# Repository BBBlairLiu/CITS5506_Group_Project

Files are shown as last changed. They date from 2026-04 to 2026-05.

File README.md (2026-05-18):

# SmartSan IoT Group Project

SmartSan is an IoT-based hand sanitiser monitoring system designed for CITS5506.  
The current prototype design combines automatic dispensing, sanitizer level monitoring, and a simple browser-based monitoring interface.

## Current Repository Status

This repository currently includes a mock dashboard, software planning documents, and an ESP32 firmware skeleton for the SmartSan system.

At this stage:
- the dashboard is built with HTML, CSS, and JavaScript
- the displayed values are **mock data following the planned ESP32/Blynk data contract**
- the firmware can run with simulated hardware while the real components are in transit
- the page is intended to simulate the future monitoring workflow before hardware arrives

## Current Design Overview

The current SmartSan design is based on:
- **ESP32** as the main controller
- **VL53L1X distance sensor** for hand detection
- **servo motor** for bottle pressing
- **HX711 load cell** for weight-based refill estimation
- **Blynk dashboard** as the primary mobile dashboard
- **local browser interface** as a mock/demo fallback

The current software flow is planned as:

Distance sensor detects hand -> servo presses bottle -> usage count updates -> liquid weight and remaining percentage are updated -> refill status is checked -> status is sent to Blynk/dashboard

## Dashboard Features (Mock Version)

The current dashboard shows:
- usage count
- liquid weight
- remaining level percentage
- sanitizer status
- device state
- device online state
- refill threshold
- last dispense time
- sync status and last sync time
- last updated time

It also includes demo controls for simulated sensor dispense, manual dispense, alert reset, system enable/disable, simulated sync failure, and an event timeline.

## Firmware Skeleton

The ESP32 Arduino sketch is available at:

- `firmware/SmartSanESP32/SmartSanESP32.ino`

By default, the sketch uses mock hardware mode:

- Serial Monitor input `d` simulates a valid hand-detection event
- Blynk virtual pins are updated using the planned dashboard data contract
- hardware adapter functions are isolated so they can later be replaced with real IR, servo, and HX711 logic

Before uploading to an ESP32, copy `firmware/SmartSanESP32/secrets.example.h` to `firmware/SmartSanESP32/secrets.h` and fill in local Blynk and Wi-Fi values. The local `secrets.h` file is ignored by git.

For team testing instructions, follow `docs/team_testing_guide.md`.

## Software Documents

- `docs/software_functionalities.md` summarises the software features.
- `docs/blynk_dashboard.md` defines the Blynk dashboard widgets and virtual pins.
- `docs/data_contract.md` defines the fields shared between firmware and dashboard.
- `docs/integration_test_plan.md` lists the hardware integration and evidence checklist.
- `docs/software_test_checklist.md` lists software-only validation scenarios before hardware integration.
- `docs/team_testing_guide.md` gives the step-by-step Blynk, mock firmware, and hardware test handoff.

## How to Run

Open the dashboard file in a browser.

### Option 1
Open the HTML file directly:
- `src/index.html`

### Option 2
Use **Live Server** in VS Code:
1. Open the project in VS Code
2. Right-click the HTML file
3. Select **Open with Live Server**

## Project Structure

```text
CITS5506_GROUP_PROJECT/
├─ docs/
│  ├─ blynk_dashboard.md
│  ├─ data_contract.md
│  ├─ integration_test_plan.md
│  ├─ software_test_checklist.md
│  └─ software_functionalities.md
├─ firmware/
│  └─ SmartSanESP32/
│     └─ SmartSanESP32.ino
├─ src/
│  └─ index.html
└─ README.md

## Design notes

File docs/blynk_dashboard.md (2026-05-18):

# SmartSan Blynk Dashboard Setup

This project uses Blynk as the primary dashboard platform because it gives the team a mobile-friendly demo quickly while the hardware and 3D printed enclosure are still being prepared.

## Blynk Template

Create one Blynk template for the prototype:

- Template name: `SmartSan Prototype`
- Hardware: `ESP32`
- Connection type: `WiFi`
- Device name: `SmartSan Demo Unit`

Keep Adafruit IO as a backup for data logging only. The main demo should use Blynk first so the flow is easy to show on a phone.

## Virtual Pin Map

| Virtual Pin | Field | Type | Unit | Direction | Suggested Widget |
| --- | --- | --- | --- | --- | --- |
| `V0` | `usageCount` | Integer | events | ESP32 to Blynk | Value Display |
| `V2` | `remainingPercent` | Integer | % | ESP32 to Blynk | Gauge |
| `V3` | `refillAlert` | Integer | 0/1 | ESP32 to Blynk | LED or Label |
| `V4` | `deviceState` | String | none | ESP32 to Blynk | Label |
| `V5` | `lastDispenseAt` | String | time | ESP32 to Blynk | Label |
| `V6` | `deviceOnline` | Integer | 0/1 | ESP32 to Blynk | LED |
| `V7` | `liquidWeightGrams` | Double | g | ESP32 to Blynk | Value Display or Chart |
| `V8` | `distanceMm` | Integer | mm | ESP32 to Blynk | Value Display |
| `V9` | `lastDispenseGrams` | Double | g | ESP32 to Blynk | Value Display |
| `V10` | `manualDispense` | Integer | 0/1 | Blynk to ESP32 | Button |
| `V11` | `resetAlert` | Integer | 0/1 | Blynk to ESP32 | Button |
| `V12` | `systemEnabled` | Integer | 0/1 | Blynk to ESP32 | Switch |

## Blynk Console Changes for Weight-Based Firmware

Update the existing template datastreams before uploading the hardware-enabled firmware:

1. Edit `V7`:
   - Name: `liquidWeightGrams`
   - Data type: `Double`
   - Units: `g`
   - Min: `0`
   - Max: `700`
   - Decimals: `1`
2. Add `V8`:
   - Name: `distanceMm`
   - Data type: `Integer`
   - Units: `mm`
   - Min: `0`
   - Max: `2000`
3. Add `V9`:
   - Name: `lastDispenseGrams`
   - Data type: `Double`
   - Units: `g`
   - Min: `0`
   - Max: `100`
   - Decimals: `1`
4. Keep `V2` as `remainingPercent` with Min `0`, Max `100`, and units `%`.
5. Keep `V3` as `refillAlert` with Min `0`, Max `1`.
6. Click **Save And Apply** after editing the datastreams.

## Dashboard Layout

Use this layout for the first demo:

- Top row: device online, system state, refill alert.
- Main metrics: usage count, liquid weight, remaining percentage.
- Diagnostics: distance reading and last dispense grams.
- Activity: last dispense time.
- Controls: manual dispense, reset alert, system enable switch.

## Update Rules

- Send status updates every 5 seconds while idle.
- Send immediate updates after a valid dispense event.
- Send immediate updates when refill alert changes.
- Treat `refillAlert = 1` when `remainingPercent <= 10`.
- Use `systemEnabled = 0` to block manual and sensor-triggered dispensing during testing.

## Demo Notes

The Blynk dashboard should be ready before the hardware arrives. During early testing, the ESP32 sketch can send simulated values to these virtual pins so the team can verify the dashboard workflow without sensors connected.

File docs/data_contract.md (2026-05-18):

# SmartSan Data Contract

This document defines the software interface between the ESP32 firmware, the Blynk dashboard, and the local mock dashboard.

## Status Payload

| Field | Type | Unit | Source | Update Frequency | Description |
| --- | --- | --- | --- | --- | --- |
| `usageCount` | Integer | events | ESP32 state | After dispense and every 5 seconds | Total valid dispense events since reset |
| `liquidWeightGrams` | Float | g | HX711 load cell | Every 5 seconds and after dispense | Estimated remaining liquid weight after empty-bottle tare |
| `remainingPercent` | Integer | % | ESP32 calculation | After measurement and after dispense | Estimated sanitizer remaining percentage from liquid weight |
| `distanceMm` | Integer | mm | VL53L1X distance sensor | Every 5 seconds and during detection | Corrected hand-distance reading |
| `lastDispenseGrams` | Float | g | ESP32 calculation | After dispense stabilisation | Estimated liquid used by the latest accepted dispense |
| `refillAlert` | Boolean | none | ESP32 threshold logic | On change and every 5 seconds | `true` when refill is required |
| `deviceState` | String | none | ESP32 state machine | On state change | Current software state |
| `deviceOnline` | Boolean | none | ESP32/Blynk connection | Every 5 seconds | Whether the device is connected |
| `systemEnabled` | Boolean | none | Blynk/local control | On change | Allows or blocks dispensing |
| `handDetected` | Boolean | none | VL53L1X distance range | During detection and state update | Whether a valid hand event is active |
| `lastDispenseAt` | String | time | ESP32 clock/runtime | After dispense | Last successful dispense timestamp or runtime label |
| `message` | String | none | ESP32 state machine | On state change | Human-readable dashboard message |

## State Values

Use these values consistently in firmware and dashboard displays:

- `IDLE`
- `HAND_DETECTED`
- `DISPENSING`
- `WAIT_STABILISE`
- `CHECK_REFILL`
- `UPDATE_STATUS`
- `REFILL_REQUIRED`
- `DISABLED`
- `ERROR`

## Thresholds and Timing

| Name | Default | Purpose |
| --- | --- | --- |
| `fullLiquidGrams` | `600 g` | Weight used as the full-liquid calibration reference for the demo |
| `refillAlertPercent` | `10%` | Trigger refill alert when remaining percentage is at or below this value |
| `minHandDistanceMm` | `70 mm` | Lower bound of distance-trigger detection range |
| `maxHandDistanceMm` | `150 mm` | Upper bound of distance-trigger detection range |
| `dispenseLockoutMs` | `2000 ms` | Prevent repeated dispensing from one hand gesture |
| `stabiliseDelayMs` | `1200 ms` | Wait after servo movement before calculating post-dispense weight |
| `statusIntervalMs` | `5000 ms` | Regular idle dashboard update interval |

## Alert Logic

The remaining percentage is:

```text
remainingPercent = clamp((liquidWeightGrams / fullLiquidGrams) * 100, 0, 100)
```

The refill condition is:

```text
refillAlert = remainingPercent <= refillAlertPercent
```

The latest dispense amount is:

```text
lastDispenseGrams = max(previousLiquidWeightGrams - currentLiquidWeightGrams, 0)
```

## Control Inputs

| Control | Source | Expected Value | Behaviour |
| --- | --- | --- | --- |
| `manualDispense` | Blynk button or mock dashboard | `1` when pressed | Runs one dispense cycle if `systemEnabled = true` |
| `resetAlert` | Blynk button or mock dashboard | `1` when pressed | Clears the visible alert after refill/testing |
| `systemEnabled` | Blynk switch or mock dashboard | `0` or `1` | Disables or enables automatic and manual dispensing |

## Hardware-Abstraction Rule

Before hardware arrives, firmware functions may return simulated values. After hardware arrives, the hardware adapter functions should remain isolated:

- `readHandDetected()`
- `performDispense()`
- `readWeightMeasurement()`
- `sampleMeasurements()`

The state machine, Blynk virtual pin mapping, and dashboard fields should remain unchanged.

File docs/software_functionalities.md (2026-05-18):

# SmartSan Software Functionalities

This document summarises the software functionalities for the current SmartSan design.

## Current Design Context

The current SmartSan prototype is based on:
- ESP32 as the main controller
- VL53L1X distance sensor for hand detection
- Servo motor for bottle pressing
- HX711 load cell for sanitizer liquid-weight monitoring
- Blynk dashboard as the primary mobile interface
- Local browser interface as a mock/demo fallback

The current direction is to:
- use liquid weight as the current level-monitoring method
- keep pump-count estimation only as a mock-mode fallback
- use the distance sensor as the primary automatic trigger
- focus first on a reliable monitoring workflow instead of advanced analytics
- use simulated sensor values before hardware arrives so the software flow can be tested early

---

## Main Software Functions

### 1. Hand Detection
The system continuously reads the VL53L1X distance sensor and decides whether a valid hand-detection event has occurred.

**Purpose**
- detect a user hand in the valid sensing range
- avoid false triggers from small fluctuations

**Input**
- corrected distance reading in millimetres

**Output**
- `handDetected = true/false`

---

### 2. Dispensing Control
Once a valid hand is detected, the ESP32 triggers the servo motor to press the sanitizer bottle once and return to its initial position.

**Purpose**
- perform one valid dispense action
- prevent repeated dispensing from one gesture

**Input**
- `handDetected`

**Output**
- one dispense event
- servo press-and-return cycle completed

---

### 3. Usage Event Recording
Each successful dispense is recorded as one valid usage event.

**Purpose**
- track how many times the dispenser has been used
- connect physical action to monitoring data

**Input**
- dispense event

**Output**
- `usageCount++`
- latest usage event updated

---

### 4. Liquid Weight Tracking
The system tracks the estimated grams of liquid left in the current refill cycle.

**Purpose**
- provide a practical remaining-level estimate from the calibrated load cell

**Input**
- HX711 raw reading
- empty-bottle zero point
- calibration factor

**Output**
- `liquidWeightGrams`
- `remainingPercent`

---

### 5. Dispense Lockout and Stabilisation Window
The system applies lockout and delay logic to avoid repeated dispensing from one gesture.

**Purpose**
- prevent accidental rapid re-triggering
- keep event counting reliable during servo motion

**Logic**
- lockout period after dispense
- state transition delay before refill check

**Output**
- one counted event per accepted dispense cycle

---

### 6. Sanitizer Level Monitoring
The remaining percentage is compared with a refill threshold to determine whether the sanitizer level is normal or low.

**Purpose**
- monitor remaining sanitizer level
- support condition-based refill alerts

**Input**
- `liquidWeightGrams`
- `remainingPercent`
- `refillAlertPercent`

**Output**
- `sanitizerLow = true/false`

---

### 7. Refill Alert Logic
When the sanitizer level falls below the refill threshold, the system updates the warning state.

**Purpose**
- provide a clear low-sanitizer alert

**Input**
- `sanitizerLow`

**Output**
- `warningStatus = LOW/NORMAL`

---

### 8. Device State Management
The software manages the sequence of system states so the workflow happens in the correct order.

**Purpose**
- keep the workflow organised
- make debugging easier

**Example States**
- `IDLE`
- `HAND_DETECTED`
- `DISPENSING`
- `WAIT_STABILISE`
- `CHECK_REFILL`
- `UPDATE_STATUS`

---

### 9. Wi-Fi / Blynk Status Transmission
The ESP32 sends the latest system variables to Blynk and can also support the local browser mock interface during development.

**Purpose**
- make monitoring information visible through the web page

**Input**
- usage count
- sanitizer status
- device state

**Output**
- updated values available to the dashboard

---

### 10. Web Monitoring Display and Sync Status
The browser page shows key monitoring information plus sync health for testing without hardware.

**Current Display Fields**
- usage count
- liquid weight
- remaining percentage
- sanitizer status
- device state
- refill threshold
- system message
- sync status and event timeline

---

## Suggested MVP Workflow

The current minimum viable software flow is:

`distance sensor detects hand -> servo presses bottle -> usage count updates -> liquid weight is updated -> refill status is checked -> status is sent by Wi-Fi -> browser page displays result`

---

## Current Priority

The current software priority is:
1. hand detection
2. dispensing control
3. usage event recording
4. liquid weight tracking
5. lockout and stabilisation window
6. sanitizer level monitoring
7. refill alert logic
8. Wi-Fi status transmission
9. web monitoring display

The implementation details are split across:
- `blynk_dashboard.md` for Blynk virtual pins and widgets
- `data_contract.md` for shared ESP32/dashboard fields
- `integration_test_plan.md` for hardware arrival and final demo testing

---

## Not the Current Priority

At this stage, the software should not focus too much on:
- advanced analytics
- prediction models
- too many admin-side functions
- advanced prediction beyond the current distance/weight workflow

These can be considered later after the basic monitoring workflow is stable.

---

## Summary

The software for the current SmartSan design is intended to support:
- automatic hand detection
- controlled dispensing
- usage recording
- weight-based level monitoring
- refill warning
- browser-based monitoring

The main goal for this stage is to build a simple, reliable, and testable monitoring workflow before full hardware integration.

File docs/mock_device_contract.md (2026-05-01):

# SmartSan Firmware Output Contract

## Update Behaviour

Immediate update on:
- state change
- valid dispense
- refill reset
- system enable/disable

Periodic idle update:
- every 5 seconds

---

## Output Fields

| Field | Type | Unit | Example | Update Trigger |
|---|---|---|---|---|
| usageCount | integer | events | 14 | dispense + periodic |
| remainingPumps | integer | pumps | 11 | dispense + reset |
| remainingPercent | integer | % | 44 | dispense + reset |
| refillAlert | boolean | true/false | false | refill threshold |
| deviceState | string | enum | IDLE | state transition |
| deviceOnline | boolean | true/false | true | periodic |
| lastDispenseAt | string | ms/time | 124920 | dispense |

---

## State Enum Values

- IDLE
- HAND_DETECTED
- DISPENSING
- WAIT_STABILISE
- CHECK_REFILL
- UPDATE_STATUS
- REFILL_REQUIRED
- DISABLED
- ERROR

---

# Mock Trace 1 — Normal Dispense

t=0s  
state=IDLE  
remainingPumps=25  
refillAlert=false

t=1s  
state=HAND_DETECTED

t=2s  
state=DISPENSING

t=3s  
state=WAIT_STABILISE

t=4s  
state=CHECK_REFILL  
remainingPumps=24

t=5s  
state=UPDATE_STATUS

t=6s  
state=IDLE

---

# Mock Trace 2 — Refill Required

t=0s  
state=IDLE  
remainingPumps=1

t=1s  
state=HAND_DETECTED

t=2s  
state=DISPENSING

t=3s  
state=WAIT_STABILISE

t=4s  
state=CHECK_REFILL  
remainingPumps=0  
refillAlert=true

t=5s  
state=REFILL_REQUIRED

---

# Mock Trace 3 — Recovery / Reset

t=0s
state=REFILL_REQUIRED
remainingPumps=0
refillAlert=true

t=1s
resetAlert=true

t=2s
state=IDLE
remainingPumps=25
refillAlert=false

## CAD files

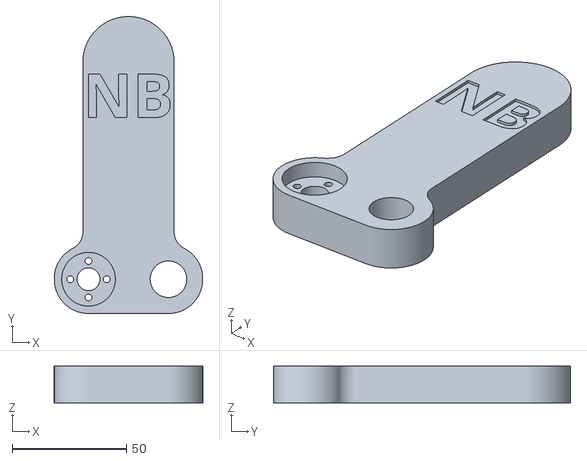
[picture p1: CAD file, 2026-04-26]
docs/Presser.stl
65.0 x 130.0 x 16.0

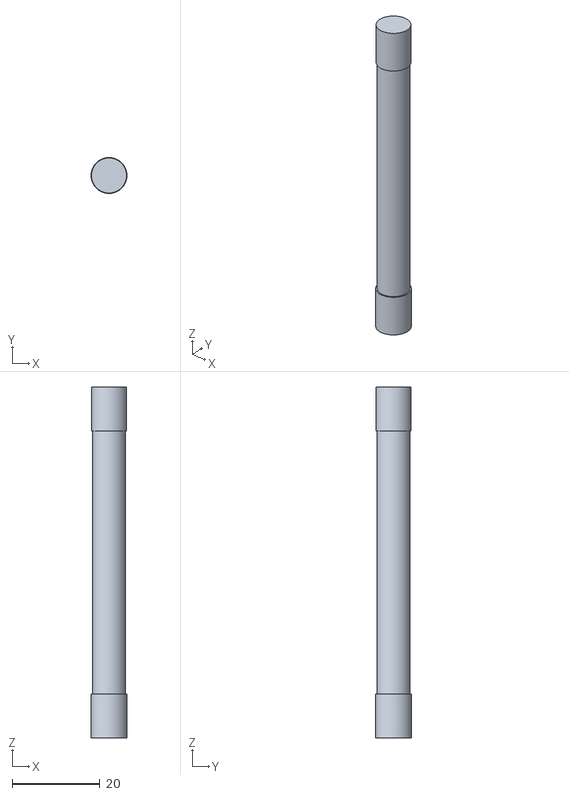
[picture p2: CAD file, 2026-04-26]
docs/Rod.stl
8.20 x 8.20 x 80.0

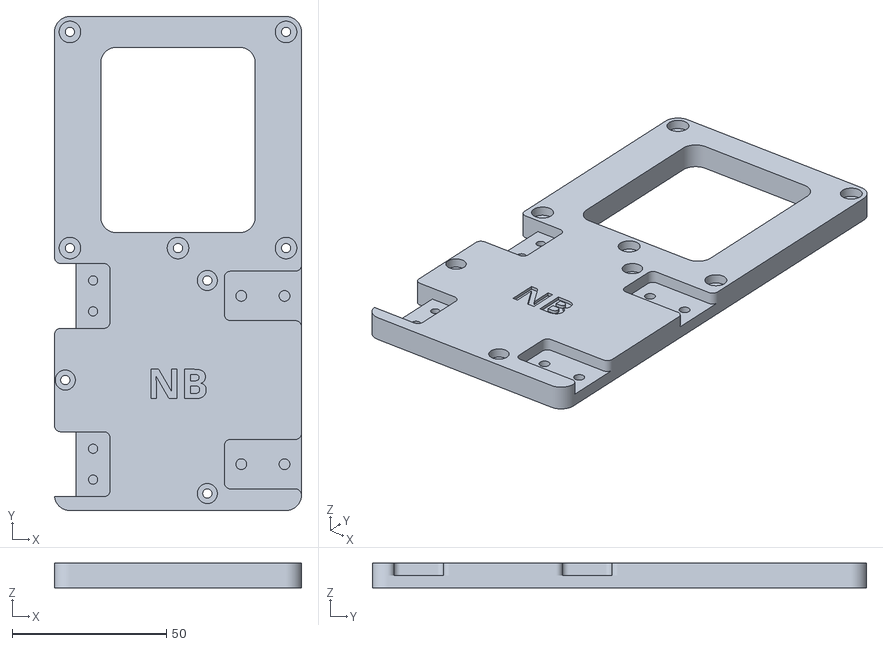
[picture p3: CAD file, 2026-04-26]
docs/Cover.stl
80.0 x 160.0 x 8.00

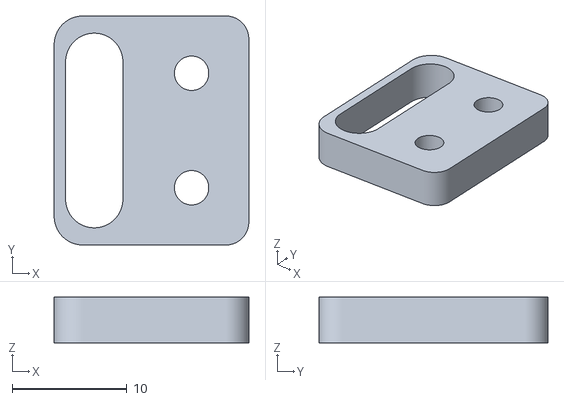
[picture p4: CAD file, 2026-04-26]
docs/Grip.stl
17.0 x 20.0 x 4.00

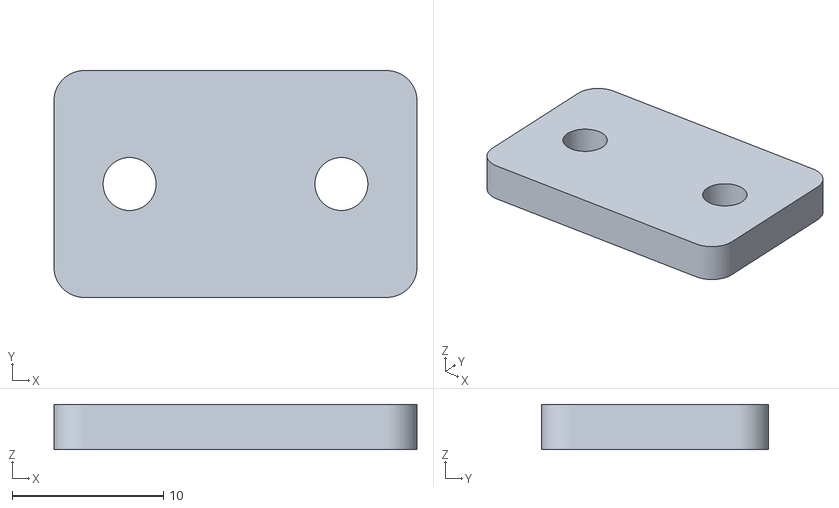
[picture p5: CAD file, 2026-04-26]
docs/Tensioner.stl
24.0 x 15.0 x 3.00

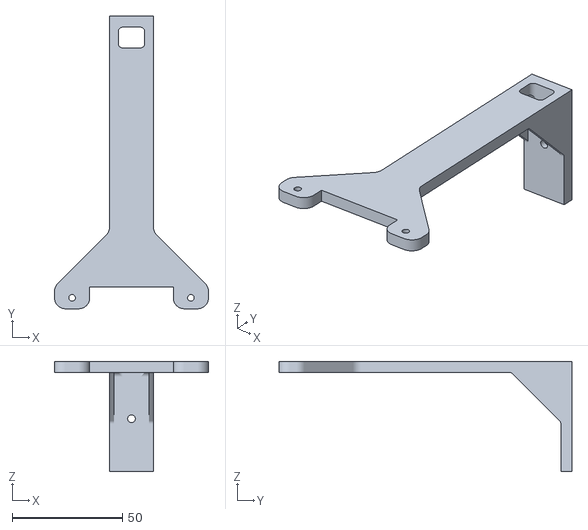
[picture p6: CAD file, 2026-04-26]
docs/IR+holder.stl
70.0 x 133.0 x 50.0

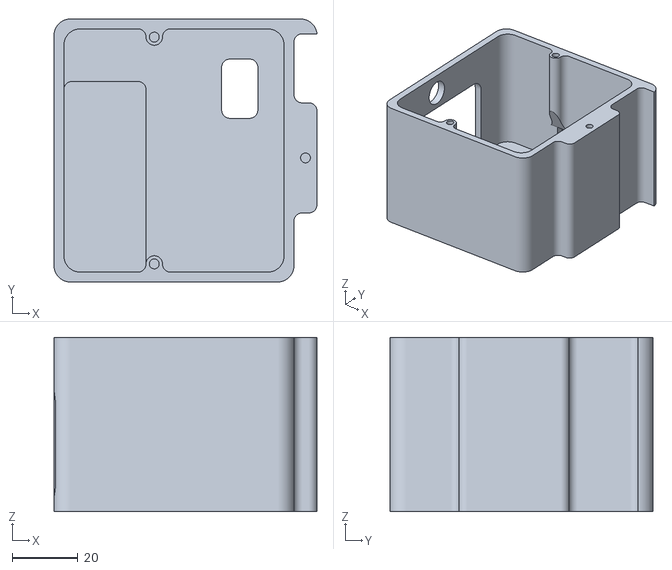
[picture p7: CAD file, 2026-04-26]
docs/Electronics+Case.stl
80.0 x 80.0 x 53.0

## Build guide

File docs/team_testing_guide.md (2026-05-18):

# SmartSan Team Testing Guide

Use this guide to test the current SmartSan ESP32 and Blynk integration before the final hardware assembly.

## Current Test Scope

The main firmware is:

```text
firmware/SmartSanESP32/SmartSanESP32.ino
```

Do not use `sketch_may7a` for Blynk testing. That sketch only toggles GPIO 2 and does not contain the SmartSan state machine.

The current firmware starts in mock hardware mode:

```cpp
#define USE_MOCK_HARDWARE 1
```

In this mode, the real VL53L1X distance sensor, HX711 load cell, and servo are not used. A Serial Monitor command simulates a hand-detection event.

## One-Time Local Setup

1. Open `firmware/SmartSanESP32/SmartSanESP32.ino` in Arduino IDE.
2. Copy `firmware/SmartSanESP32/secrets.example.h` to `firmware/SmartSanESP32/secrets.h`.
3. Fill `secrets.h` with the Blynk template ID, Blynk auth token, Wi-Fi SSID, and Wi-Fi password.
4. Keep `secrets.h` local. It is ignored by git and should not be pushed.
5. In Arduino IDE, select the ESP32 board and the correct serial port.
6. Set Serial Monitor baud rate to `115200`.

## Blynk Datastream Contract

| Pin | Name | Direction | Expected Use |
| --- | --- | --- | --- |
| `V0` | `usageCount` | ESP32 to Blynk | Total accepted dispense count |
| `V2` | `remainingPercent` | ESP32 to Blynk | Estimated remaining percentage |
| `V3` | `refillAlert` | ESP32 to Blynk | `1` when refill is required |
| `V4` | `deviceState` | ESP32 to Blynk | State string such as `IDLE` or `DISPENSING` |
| `V5` | `lastDispenseAt` | ESP32 to Blynk | Runtime label for last dispense |
| `V6` | `deviceOnline` | ESP32 to Blynk | `1` when Blynk is connected |
| `V7` | `liquidWeightGrams` | ESP32 to Blynk | Estimated liquid weight in grams |
| `V8` | `distanceMm` | ESP32 to Blynk | Corrected distance sensor reading |
| `V9` | `lastDispenseGrams` | ESP32 to Blynk | Estimated grams used by the latest dispense |
| `V10` | `manualDispense` | Blynk to ESP32 | Button input, send `1` to trigger one cycle |
| `V11` | `resetAlert` | Blynk to ESP32 | Button input, send `1` to reset refill count |
| `V12` | `systemEnabled` | Blynk to ESP32 | Switch input, `1` enabled and `0` disabled |

## Mock Firmware Test

1. Upload the firmware with `USE_MOCK_HARDWARE` set to `1`.
2. Open Serial Monitor at `115200`.
3. Send `d` or `D`.
4. Expected Serial Monitor output includes:

```text
[MOCK] Trigger dispense
[MOCK] Dispense start
[MOCK] Dispense end
[COUNT] Total: 1 | Session: 1 | Remaining %: 96 | Liquid g: 576.0
```

5. Expected Blynk changes:
   - `usageCount` increases by 1.
   - `liquidWeightGrams` decreases.
   - `remainingPercent` updates.
   - `deviceState` moves through `HAND_DETECTED`, `DISPENSING`, `WAIT_STABILISE`, then back to `IDLE`.

## Blynk Control Test

Run these tests after the mock firmware test works.

| Test | Action | Expected Result |
| --- | --- | --- |
| Manual dispense | Press the `manualDispense` widget mapped to `V10` | One dispense cycle runs |
| Disable system | Set `systemEnabled` on `V12` to `0` | Device state becomes `DISABLED`; dispense is blocked |
| Re-enable system | Set `systemEnabled` on `V12` to `1` | Device returns to `IDLE` or `REFILL_REQUIRED` |
| Reset refill alert | Press `resetAlert` on `V11` | Mock mode resets liquid weight to `600 g`; real mode rereads the load cell and clears only if weight is above the refill threshold |

## If `d` or `D` Has No Response

Check these items in order:

1. Confirm the uploaded sketch is `firmware/SmartSanESP32/SmartSanESP32.ino`.
2. Confirm Serial Monitor is set to `115200`.
3. Confirm `USE_MOCK_HARDWARE` is `1`.
4. Confirm the ESP32 has uploaded successfully. The current firmware uses non-blocking Blynk connection logic, so Serial Monitor samples should still print even if Wi-Fi/Blynk is not connected yet.
5. Confirm `systemEnabled` is `1` in Blynk.
6. Wait at least 2 seconds between repeated sends because the firmware has a dispense lockout.

## Real Hardware Test

Only move to this phase after the mock and Blynk control tests pass.

1. Install the `VL53L1X`, `HX711`, and `ESP32Servo` libraries in Arduino IDE.
2. Change the firmware to:

```cpp
#define USE_MOCK_HARDWARE 0
```

3. Select the board package that supports the connected XIAO ESP32 `D1`-style pin labels.
4. Wire the hardware according to the current firmware constants:

| Hardware | Board Pin | Firmware Constant |
| --- | --- | --- |
| Servo signal | `D1` | `PIN_SERVO` |
| HX711 DT / DOUT | `D2` | `PIN_LOADCELL_DOUT` |
| HX711 SCK / CLK | `D3` | `PIN_LOADCELL_SCK` |
| VL53L1X SDA | `D4` | `PIN_DISTANCE_SDA` |
| VL53L1X SCL | `D5` | `PIN_DISTANCE_SCL` |

Optional status LEDs are supported but disabled by default. Only enable them after wiring LEDs with resistors to unused pins:

| LED | Board Pin | Firmware Constant |
| --- | --- | --- |
| Green / normal | `D6` | `PIN_LED_GREEN` |
| Orange / low or disabled | `D7` | `PIN_LED_ORANGE` |
| Red / refill or error | `D8` | `PIN_LED_RED` |

To enable LEDs in real hardware mode, set:

```cpp
#define USE_MOCK_HARDWARE 0
#define ENABLE_STATUS_LEDS 1
```

5. Upload the firmware.
6. Place a hand between `70 mm` and `150 mm` from the distance sensor.
7. Expected result:
   - Serial Monitor prints `[DISTANCE] Hand detected at ... mm`.
   - Servo performs one press-and-return cycle.
   - Serial Monitor prints CSV samples with `time_ms,distance_mm,load_raw,liquid_g,remaining_percent,last_dispense_g,state,event`.
   - Blynk metrics update after the accepted cycle.

## Notes on `SmartSan_prototype_simple.ino`

The teammate-provided simplified sketch is useful as a logic reference, but do not upload it as a drop-in replacement for the current repository firmware without changes.

Main mismatches found:

| Area | Simplified sketch | Current project contract |
| --- | --- | --- |
| Hand detection | IR sensor on GPIO `2` | VL53L1X distance sensor on `D4`/`D5` |
| Servo | GPIO `5`, angle `0 -> 60` | `D1`, angle `90 -> 15` |
| HX711 | GPIO `21`/`22`, uncalibrated relative units | `D2`/`D3`, calibrated empty-bottle zero and grams conversion |
| Blynk `V2` | Current weight | `remainingPercent` |
| Blynk `V4` | Bottle status | `deviceState` |
| Blynk `V5` | Device state | `lastDispenseAt` |
| Blynk `V7` | Remaining pumps | `liquidWeightGrams` |
| Credentials | Hardcoded placeholders in the sketch | Local ignored `secrets.h` file |

The current source of truth remains:

```text
firmware/SmartSanESP32/SmartSanESP32.ino
```

## Evidence To Capture

Each tester should capture:

- One screenshot of Blynk after a successful mock `d` test.
- One screenshot or short video of the `manualDispense` Blynk control working.
- One screenshot showing `systemEnabled = 0` blocks dispensing.
- If hardware is connected, one short video of distance detection triggering the servo and Blynk updates.
- A copied CSV sample from Serial Monitor covering at least 10 dispense attempts.

Record any failure with the exact step number, Serial Monitor output, Blynk widget values, and whether mock mode or real hardware mode was used.

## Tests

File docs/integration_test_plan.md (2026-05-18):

# SmartSan Hardware Integration Test Plan

Use this checklist when the ordered hardware and 3D printed part are available. Test each subsystem before assembling the full enclosure.

## Phase 1: ESP32 and Blynk

| Test | Method | Expected Result | Evidence |
| --- | --- | --- | --- |
| Wi-Fi connection | Upload the firmware with real Wi-Fi and Blynk credentials | Device appears online in Blynk | Screenshot of online widget |
| Virtual pin update | Run mock mode and send `d` in Serial Monitor | `usageCount`, `liquidWeightGrams`, `remainingPercent`, and `deviceState` update | Screenshot of Blynk dashboard |
| Control inputs | Press manual dispense, reset alert, and system enable switch | ESP32 state changes correctly | Short video or screenshots |

## Phase 2: Distance Sensor

| Test | Method | Expected Result | Evidence |
| --- | --- | --- | --- |
| Basic detection | Print corrected VL53L1X distance reading in Serial Monitor | Hand presence is clearly detectable between 70 mm and 150 mm | Serial output screenshot |
| False trigger check | Leave the sensor idle for 2 minutes | No unexpected dispense event | Serial output or observation |
| Lockout check | Hold hand near sensor | Only one dispense event occurs until the hand leaves and re-enters the detection range | Serial output or video |

## Phase 3: Servo Mechanism

| Test | Method | Expected Result | Evidence |
| --- | --- | --- | --- |
| Servo angle sweep | Test press and return angles without sanitizer bottle | Servo moves smoothly and returns | Short video |
| Bottle press | Mount bottle and trigger one press | One usable sanitizer output is produced | Short video |
| Power stability | Trigger repeated presses | ESP32 does not reset or disconnect | Observation notes |

## Phase 4: Weight and Refill Logic

| Test | Method | Expected Result | Evidence |
| --- | --- | --- | --- |
| Weight update | Trigger repeated dispense cycles in real hardware mode | `liquidWeightGrams` decreases after accepted cycles | Serial CSV output |
| Lockout safety | Hold trigger input active | Counter increases once per lockout window | Serial output or video |
| Refill threshold | Reduce measured liquid until `remainingPercent <= 10` | `refillAlert` becomes true and state enters `REFILL_REQUIRED` | Dashboard screenshot |
| Alert reset | Refill bottle and trigger `resetAlert` from Blynk | Weight is reread and alert clears when above threshold | Dashboard screenshot |

## Phase 5: Full System

| Test | Method | Expected Result | Evidence |
| --- | --- | --- | --- |
| End-to-end dispense | Hand enters distance trigger range | Servo presses, usage count increments, liquid weight updates, dashboard refreshes | Video of complete flow |
| Low sanitizer flow | Reduce measured liquid until `remainingPercent <= 10` | Dashboard shows refill warning | Screenshot |
| Reset after refill | Refill and press reset alert | Status returns to normal | Screenshot |
| 3D printed enclosure test | Install all components in printed structure | Distance sensor alignment, servo motion, weight readings, and sync remain reliable | Video and notes |

## Recommended Integration Order

1. Keep the firmware in mock mode until Blynk widgets and virtual pins are confirmed.
2. Switch to real hardware mode and verify VL53L1X distance readings without triggering the servo repeatedly.
3. Verify HX711 weight readings with empty bottle, known 600 ml reference, and repeated stable samples.
4. Verify `performDispense()` with real servo control and confirm one cycle per trigger.
5. Validate usage count, liquid weight, remaining percentage, and alert logic with repeated trigger tests and reset operations.
6. Assemble the 3D printed structure only after the electronics work on the bench.
7. Recalibrate servo angles and load cell readings after final assembly.

## Demo Acceptance Criteria

The final demo is acceptable when one hand-triggered event can reliably produce this complete chain:

```text
distance detection -> servo press -> usage count +1 -> weight update -> refill decision -> Blynk/dashboard update
```

Collect at least one screenshot or short video for each major subsystem. These become useful evidence for the final report and presentation.

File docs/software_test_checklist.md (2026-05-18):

# SmartSan Software Test Checklist

This checklist focuses on software functionality that can be validated before full hardware integration.

## Dashboard and State Flow

| Test ID | Scenario | Steps | Expected Result |
| --- | --- | --- | --- |
| SW-01 | Sensor-triggered dispense | Click `Simulate Sensor Dispense` | State transitions through `HAND_DETECTED` -> `DISPENSING` -> `WAIT_STABILISE` -> `IDLE/REFILL_REQUIRED` |
| SW-02 | Manual dispense command | Click `Manual Dispense` | One dispense cycle is executed and `usageCount` increments by 1 |
| SW-03 | Single-cycle safety | Click dispense repeatedly during one running cycle | Only one active cycle runs, buttons remain disabled until cycle ends |
| SW-04 | Refill alert trigger | Reduce mock/real liquid level until `remainingPercent` reaches threshold | `Sanitizer Status` changes to `LOW` and state moves to `REFILL_REQUIRED` |
| SW-05 | Alert reset path | Click `Reset Alert` after refill or mock reset | Liquid weight/percentage returns to a normal range and warning returns to `NORMAL` |

## Sync and Failure Handling

| Test ID | Scenario | Steps | Expected Result |
| --- | --- | --- | --- |
| SW-06 | Healthy sync loop | Keep dashboard open for 15+ seconds | `Sync Status` remains `HEALTHY` and `Last Sync` keeps updating |
| SW-07 | Simulated sync failure | Enable `Simulate sync failure` toggle | `Sync Status` changes to `DEGRADED` and event timeline logs failure |
| SW-08 | Recovery after failure | Disable `Simulate sync failure` toggle | Sync returns to `HEALTHY`, device returns online, event timeline records recovery |

## Control Safety and Operator Flow

| Test ID | Scenario | Steps | Expected Result |
| --- | --- | --- | --- |
| SW-09 | Disable system lock | Turn off `System enabled` | State changes to `DISABLED`, manual/sensor dispense actions are blocked |
| SW-10 | Re-enable system | Turn on `System enabled` | State returns to `IDLE` or `REFILL_REQUIRED` based on alert status |
| SW-11 | Dashboard reset | Click `Reset Dashboard` | Counters, status, sync, and timeline reset to defaults |

## Low-Data Demo Features

| Test ID | Scenario | Steps | Expected Result |
| --- | --- | --- | --- |
| SW-12 | Session summary update | Run 3-5 dispense cycles | `Session Dispenses` increments and `Usage Intensity` updates from LOW to MEDIUM |
| SW-13 | Rule-based refill risk | Reduce remaining percentage to low values | `Refill Risk` changes from LOW/MEDIUM/HIGH/CRITICAL according to remaining percentage |
| SW-14 | Operator hint behavior | Toggle sync failure, disable system, and trigger refill required | `Operator Hint` updates to actionable guidance for each state |

## Evidence to Capture

- 1 screenshot for normal dispense flow (`SW-01`).
- 1 screenshot for refill alert (`SW-04`).
- 1 screenshot for degraded sync and recovery (`SW-07`, `SW-08`).
- 1 short video showing disabled/enabled safety lock behavior (`SW-09`, `SW-10`).
- 1 screenshot showing session summary + rule-based insights (`SW-12`, `SW-13`, `SW-14`).

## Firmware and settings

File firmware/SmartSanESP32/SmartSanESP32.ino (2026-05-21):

/*
  SmartSan ESP32 firmware.

  Mock mode keeps the original Serial Monitor test path. Real hardware mode uses
  the hardware group's VL53L1X distance sensor, HX711 load cell, servo logic,
  and optional status LEDs.
*/

// Blynk configuration
#define BLYNK_TEMPLATE_NAME "SmartSan Prototype"

// Copy secrets.example.h to secrets.h and fill in local credentials before upload.
// secrets.h is intentionally ignored by git so Blynk tokens and Wi-Fi passwords
// are not pushed to the remote repository.
#if __has_include("secrets.h")
#include "secrets.h"
#else
#define BLYNK_TEMPLATE_ID "REPLACE_WITH_TEMPLATE_ID"
#define BLYNK_AUTH_TOKEN "REPLACE_WITH_DEVICE_AUTH_TOKEN"
const char WIFI_SSID[] = "REPLACE_WITH_WIFI_NAME";
const char WIFI_PASS[] = "REPLACE_WITH_WIFI_PASSWORD";
#endif

// Set to 0 after the hardware wiring and Arduino libraries are ready.
#define USE_MOCK_HARDWARE 0

// Status LEDs: green/yellow/red show fill level, white shows hand detection.
#define ENABLE_STATUS_LEDS 1

// Temporary hardware bypass: keep this at 0 while HX711 wiring is being checked.
// Distance sensing, servo dispensing, Serial output, and Blynk updates still run.
#define ENABLE_HX711 1

// Temporary test bypass: set to 0 only while the distance sensor I2C issue is being debugged.
// Manual Blynk dispense still works; hand-triggered dispense is disabled.
#define ENABLE_DISTANCE_SENSOR 1

#include <WiFi.h>
#include <BlynkSimpleEsp32.h>

#if !USE_MOCK_HARDWARE
#include <Wire.h>
#include <VL53L1X.h>
#include <ESP32Servo.h>
#if ENABLE_HX711
#include "HX711.h"
#endif
#endif

// Hardware pin map from project_iot_adjustment.ino.
// D pin labels are used by the selected XIAO ESP32 board package in Arduino IDE.
#if !USE_MOCK_HARDWARE
const int PIN_SERVO = D1;
#if ENABLE_HX711
const int PIN_LOADCELL_DOUT = D2;
const int PIN_LOADCELL_SCK = D3;
#endif
const int PIN_DISTANCE_SDA = D4;
const int PIN_DISTANCE_SCL = D5;
#endif

#if !USE_MOCK_HARDWARE && ENABLE_STATUS_LEDS
// Optional status LEDs. Keep D1-D5 reserved for servo, HX711, and VL53L1X.
const int PIN_LED_GREEN = D8;
const int PIN_LED_YELLOW = D7;
const int PIN_LED_RED = D9;
const int PIN_LED_WHITE = D0;
const bool LED_ACTIVE_HIGH = true;
const int LED_TEST_STEP_MS = 1500;
const int LED_TEST_OFF_STEP_MS = 2000;
#endif

// Distance trigger settings
const int MIN_HAND_DISTANCE_MM = 70;
const int MAX_HAND_DISTANCE_MM = 150;
const int DISTANCE_OFFSET_MM = 5;
const int DISTANCE_SENSOR_PERIOD_MS = 20;
const int DISTANCE_SENSOR_TIMEOUT_MS = 200;

// Servo settings from the hardware integration sketch
const int SERVO_HOME_DEG = 90;
const int SERVO_PRESS_DEG = 15;
const int SERVO_STEP_DELAY_MS = 8;
const int SERVO_HOLD_MS = 450;
const int SERVO_RETURN_SETTLE_MS = 250;

// HX711 load cell calibration from the hardware group.
// Empty bottle is treated as 0 g liquid weight.
const long LOADCELL_ZERO_RAW = 1045992;
const float LOADCELL_CALIBRATION_FACTOR = 2153.3;
const float FULL_LIQUID_GRAMS = 250.0;
const float EMPTY_NOISE_GRAMS = 5.0;
const int REFILL_ALERT_PERCENT = 25;
const int LED_RED_BELOW_PERCENT = 25;
const int LED_YELLOW_MAX_PERCENT = 50;

// Blynk virtual pin definitions
const int PIN_USAGE_COUNT = V0;
const int PIN_REMAINING_PERCENT = V2;
const int PIN_REFILL_ALERT = V3;
const int PIN_DEVICE_STATE = V4;
const int PIN_LAST_DISPENSE_AT = V5;
const int PIN_DEVICE_ONLINE = V6;
const int PIN_LIQUID_WEIGHT_GRAMS = V7;
const int PIN_DISTANCE_MM = V8;
const int PIN_LAST_DISPENSE_GRAMS = V9;
const int PIN_MANUAL_DISPENSE = V10;
const int PIN_RESET_ALERT = V11;
const int PIN_SYSTEM_ENABLED = V12;
const int PIN_CALIBRATE_ZERO = V13;
const int PIN_CALIBRATE_FULL = V14;
const int PIN_LED_TEST = V15;
const int PIN_CALIBRATION_STATUS = V16;

// Device and state machine variables
const int MAX_PUMPS = 25;
const unsigned long DISPENSE_LOCKOUT_MS = 1000;
const unsigned long STABILISE_DELAY_MS = 700;
const unsigned long STATUS_INTERVAL_MS = 5000;
const unsigned long MEASUREMENT_INTERVAL_MS = 250;
const unsigned long BLYNK_RECONNECT_INTERVAL_MS = 10000;
const unsigned long WIFI_STATUS_LOG_INTERVAL_MS = 5000;
const unsigned long STABILISE_TIMEOUT_MS = 5000;
const unsigned long ERROR_RECOVERY_MS = 4000;
const unsigned long HX711_READY_TIMEOUT_MS = 5000;
const unsigned long HX711_READY_RETRY_MS = 100;
const unsigned long HX711_SAMPLE_TIMEOUT_MS = 300;
const int HX711_READ_SAMPLES = 3;
const int HX711_CALIBRATION_SAMPLES = 10;

enum DeviceState {
  STATE_IDLE,
  STATE_HAND_DETECTED,
  STATE_DISPENSING,
  STATE_WAIT_STABILISE,
  STATE_CHECK_REFILL,
  STATE_UPDATE_STATUS,
  STATE_REFILL_REQUIRED,
  STATE_DISABLED,
  STATE_ERROR
};

DeviceState deviceState = STATE_IDLE;

#if !USE_MOCK_HARDWARE
VL53L1X distanceSensor;
Servo dispenserServo;
#if ENABLE_HX711
HX711 scale;
#endif
#endif

int usageCount = 0;
int sessionCount = 0;
int remainingPumpsEstimate = MAX_PUMPS;
int remainingPercent = 100;
bool refillAlert = false;
bool systemEnabled = true;
bool manualDispenseRequested = false;
bool resetAlertRequested = false;
bool dispensingActive = false;
bool handPresent = false;
bool distanceSensorReady = false;
bool scaleReady = false;

long loadCellRaw = 0;
long loadCellZeroRaw = LOADCELL_ZERO_RAW;
float loadCellCalibrationFactor = LOADCELL_CALIBRATION_FACTOR;
float liquidWeightGrams = FULL_LIQUID_GRAMS;
float previousLiquidWeightGrams = FULL_LIQUID_GRAMS;
float lastDispenseGrams = 0.0;
int distanceRawMm = 0;
int distanceMm = 0;

unsigned long lastDispenseMs = 0;
unsigned long stateStartedMs = 0;
unsigned long lastStatusMs = 0;
unsigned long lastMeasurementMs = 0;
unsigned long lastErrorLogMs = 0;
unsigned long lastBlynkReconnectMs = 0;
unsigned long lastWiFiStatusLogMs = 0;
int lastWiFiStatus = -1;
bool blynkConnectedLogged = false;

bool csvHeaderPrinted = false;
String calibrationStatusMessage = "Calibration not run";

String stateToString(DeviceState state) {
  switch (state) {
    case STATE_IDLE:
      return "IDLE";
    case STATE_HAND_DETECTED:
      return "HAND_DETECTED";
    case STATE_DISPENSING:
      return "DISPENSING";
    case STATE_WAIT_STABILISE:
      return "WAIT_STABILISE";
    case STATE_CHECK_REFILL:
      return "CHECK_REFILL";
    case STATE_UPDATE_STATUS:
      return "UPDATE_STATUS";
    case STATE_REFILL_REQUIRED:
      return "REFILL_REQUIRED";
    case STATE_DISABLED:
      return "DISABLED";
    case STATE_ERROR:
      return "ERROR";
    default:
      return "UNKNOWN_STATE";
  }
}

float clampFloat(float value, float lower, float upper) {
  if (value < lower) {
    return lower;
  }

  if (value > upper) {
    return upper;
  }

  return value;
}

void updateRemainingMetrics() {
  float percent = (liquidWeightGrams / FULL_LIQUID_GRAMS) * 100.0;
  remainingPercent = (int)(clampFloat(percent, 0.0, 100.0) + 0.5);

  float pumpEstimate = (remainingPercent / 100.0) * MAX_PUMPS;
  remainingPumpsEstimate = (int)(clampFloat(pumpEstimate, 0.0, MAX_PUMPS) + 0.5);
}

void updateRefillAlert() {
  refillAlert = remainingPercent <= REFILL_ALERT_PERCENT;
}

void setupStatusLeds() {
#if !USE_MOCK_HARDWARE && ENABLE_STATUS_LEDS
  pinMode(PIN_LED_GREEN, OUTPUT);
  pinMode(PIN_LED_YELLOW, OUTPUT);
  pinMode(PIN_LED_RED, OUTPUT);
  pinMode(PIN_LED_WHITE, OUTPUT);

  digitalWrite(PIN_LED_GREEN, LED_ACTIVE_HIGH ? LOW : HIGH);
  digitalWrite(PIN_LED_YELLOW, LED_ACTIVE_HIGH ? LOW : HIGH);
  digitalWrite(PIN_LED_RED, LED_ACTIVE_HIGH ? LOW : HIGH);
  digitalWrite(PIN_LED_WHITE, LED_ACTIVE_HIGH ? LOW : HIGH);
#endif
}

void writeStatusLed(int pin, bool on) {
#if !USE_MOCK_HARDWARE && ENABLE_STATUS_LEDS
  digitalWrite(pin, on == LED_ACTIVE_HIGH ? HIGH : LOW);
#else
  (void)pin;
  (void)on;
#endif
}

void setStatusLeds(bool greenOn, bool yellowOn, bool redOn, bool whiteOn) {
#if !USE_MOCK_HARDWARE && ENABLE_STATUS_LEDS
  writeStatusLed(PIN_LED_GREEN, greenOn);
  writeStatusLed(PIN_LED_YELLOW, yellowOn);
  writeStatusLed(PIN_LED_RED, redOn);
  writeStatusLed(PIN_LED_WHITE, whiteOn);
#else
  (void)greenOn;
  (void)yellowOn;
  (void)redOn;
  (void)whiteOn;
#endif
}

void updateStatusLeds() {
  bool whiteOn = handPresent;
  bool redOn = deviceState == STATE_ERROR || remainingPercent < LED_RED_BELOW_PERCENT;
  bool yellowOn = !redOn && remainingPercent >= LED_RED_BELOW_PERCENT && remainingPercent <= LED_YELLOW_MAX_PERCENT;
  bool greenOn = !redOn && remainingPercent > LED_YELLOW_MAX_PERCENT;

  setStatusLeds(greenOn, yellowOn, redOn, whiteOn);
}

void testStatusLeds() {
  Serial.println("[LED] Test sequence: green -> yellow -> red -> white");
  setStatusLeds(false, false, false, false);
  delay(500);

  Serial.println("[LED] Testing green");
  setStatusLeds(true, false, false, false);
  delay(LED_TEST_STEP_MS);
  setStatusLeds(false, false, false, false);
  delay(500);

  Serial.println("[LED] Testing yellow");
  setStatusLeds(false, true, false, false);
  delay(LED_TEST_STEP_MS);
  setStatusLeds(false, false, false, false);
  delay(500);

  Serial.println("[LED] Testing red");
  setStatusLeds(false, false, true, false);
  delay(LED_TEST_STEP_MS);
  setStatusLeds(false, false, false, false);
  delay(500);

  Serial.println("[LED] Testing white");
  setStatusLeds(false, false, false, true);
  delay(LED_TEST_STEP_MS);
  setStatusLeds(false, false, false, false);
  delay(500);

  setStatusLeds(false, false, false, false);
  delay(300);
  updateRemainingMetrics();
  updateRefillAlert();
  updateStatusLeds();
  Serial.println("[LED] Test complete; restored normal status LEDs");
}

void forceStatusLedCommand(char command) {
  if (command == 'o' || command == 'O') {
    Serial.println("[LED] Force all off");
    setStatusLeds(false, false, false, false);
  } else if (command == 'g' || command == 'G') {
    Serial.println("[LED] Force green only");
    setStatusLeds(true, false, false, false);
  } else if (command == 'y' || command == 'Y') {
    Serial.println("[LED] Force yellow only");
    setStatusLeds(false, true, false, false);
  } else if (command == 'r' || command == 'R') {
    Serial.println("[LED] Force red only");
    setStatusLeds(false, false, true, false);
  } else if (command == 'w' || command == 'W') {
    Serial.println("[LED] Force white only");
    setStatusLeds(false, false, false, true);
  }
}

void printCsvHeaderOnce() {
  if (csvHeaderPrinted) {
    return;
  }

  Serial.println("time_ms,distance_mm,load_raw,liquid_g,remaining_percent,last_dispense_g,state,event");
  csvHeaderPrinted = true;
}

void printCsvSample(const char* eventName) {
  printCsvHeaderOnce();
  Serial.print(millis());
  Serial.print(",");
  Serial.print(distanceMm);
  Serial.print(",");
  Serial.print(loadCellRaw);
  Serial.print(",");
  Serial.print(liquidWeightGrams, 1);
  Serial.print(",");
  Serial.print(remainingPercent);
  Serial.print(",");
  Serial.print(lastDispenseGrams, 1);
  Serial.print(",");
  Serial.print(stateToString(deviceState));
  Serial.print(",");
  Serial.println(eventName);
}

void publishCalibrationStatus(const String& message) {
  calibrationStatusMessage = message;

  Serial.print("[CAL] ");
  Serial.println(message);

  if (Blynk.connected()) {
    Blynk.virtualWrite(PIN_CALIBRATION_STATUS, message);
  }
}

void printWiFiStatus(const char* context) {
  int status = WiFi.status();

  Serial.print("[WIFI] ");
  Serial.print(context);
  Serial.print(" status: ");
  Serial.print(status);

  if (status == WL_CONNECTED) {
    Serial.print(" ip: ");
    Serial.print(WiFi.localIP());
  }

  Serial.println();
}

void reportWiFiStatus(const char* context, bool forceLog) {
  int status = WiFi.status();
  bool statusChanged = status != lastWiFiStatus;

  if (statusChanged) {
    lastWiFiStatus = status;
  }

  if (forceLog || statusChanged) {
    printWiFiStatus(context);
  }

  if (statusChanged && status == WL_CONNECTED) {
    Serial.println("[WIFI] Connected");
  }
}

void reportBlynkConnection() {
  if (Blynk.connected()) {
    if (!blynkConnectedLogged) {
      Serial.println("[BLYNK] Connected");
    }
    blynkConnectedLogged = true;
  } else {
    blynkConnectedLogged = false;
  }
}

void connectBlynk() {
  WiFi.begin(WIFI_SSID, WIFI_PASS);
  Blynk.config(BLYNK_AUTH_TOKEN);

  Serial.print("[WIFI] Connecting to ");
  Serial.println(WIFI_SSID);
  reportWiFiStatus("after begin", true);

  if (!Blynk.connect(5000)) {
    Serial.println("[BLYNK] Not connected yet; local Serial testing will continue");
  }
  reportBlynkConnection();
  reportWiFiStatus("after Blynk connect attempt", true);
}

void runBlynkConnection() {
  reportWiFiStatus("loop", false);

  if (WiFi.status() != WL_CONNECTED) {
    if (millis() - lastWiFiStatusLogMs >= WIFI_STATUS_LOG_INTERVAL_MS) {
      lastWiFiStatusLogMs = millis();
      printWiFiStatus("waiting");
    }
    return;
  }

  if (!Blynk.connected() && millis() - lastBlynkReconnectMs >= BLYNK_RECONNECT_INTERVAL_MS) {
    lastBlynkReconnectMs = millis();
    Blynk.connect(1000);
    reportBlynkConnection();
  }

  if (Blynk.connected()) {
    reportBlynkConnection();
    Blynk.run();
  } else {
    blynkConnectedLogged = false;
  }
}

#if !USE_MOCK_HARDWARE
bool waitForHx711Ready(unsigned long timeoutMs);

byte scanI2CPins(const char* label, int sdaPin, int sclPin) {
  byte foundCount = 0;

  Serial.print("[I2C] ");
  Serial.print(label);
  Serial.print(" SDA=GPIO");
  Serial.print(sdaPin);
  Serial.print(", SCL=GPIO");
  Serial.println(sclPin);

  pinMode(sdaPin, INPUT_PULLUP);
  pinMode(sclPin, INPUT_PULLUP);
  delay(20);
  Serial.print("[I2C] Line level SDA=");
  Serial.print(digitalRead(sdaPin));
  Serial.print(", SCL=");
  Serial.println(digitalRead(sclPin));

  Wire.end();
  delay(20);
  Wire.begin(sdaPin, sclPin);
  for (byte address = 1; address < 127; address++) {
    Wire.beginTransmission(address);
    byte error = Wire.endTransmission();

    if (error == 0) {
      Serial.print("[I2C] Found device at 0x");
      if (address < 16) {
        Serial.print("0");
      }
      Serial.println(address, HEX);
      foundCount += 1;
    }
  }

  return foundCount;
}

void scanI2CBus() {
  byte foundCount = 0;

  Serial.println("[I2C] Expected VL53L1X address is usually 0x29");
  foundCount += scanI2CPins("Configured bus D4/D5", PIN_DISTANCE_SDA, PIN_DISTANCE_SCL);

  if (foundCount == 0) {
    Serial.println("[I2C] Trying swapped D5/D4 in case SDA/SCL are reversed");
    foundCount += scanI2CPins("Swapped bus D5/D4", PIN_DISTANCE_SCL, PIN_DISTANCE_SDA);
  }

  if (foundCount == 0) {
    Serial.println("[I2C] No devices found on configured or swapped bus.");
    Serial.println("[I2C] SDA/SCL high means the bus is idle, but no sensor is ACKing.");
  }

  Wire.end();
  delay(20);
  Wire.begin(PIN_DISTANCE_SDA, PIN_DISTANCE_SCL);
}

bool beginDistanceSensorOnPins(const char* label, int sdaPin, int sclPin) {
  Serial.print("[HW] Trying distance sensor on ");
  Serial.print(label);
  Serial.print(" SDA=GPIO");
  Serial.print(sdaPin);
  Serial.print(", SCL=GPIO");
  Serial.println(sclPin);

  Wire.end();
  delay(20);
  Wire.begin(sdaPin, sclPin);
  distanceSensor.setTimeout(DISTANCE_SENSOR_TIMEOUT_MS);

  if (!distanceSensor.init()) {
    return false;
  }

  distanceSensor.startContinuous(DISTANCE_SENSOR_PERIOD_MS);
  distanceSensorReady = true;
  Serial.print("[HW] Distance sensor started on ");
  Serial.println(label);
  return true;
}

void setupHardware() {
#if ENABLE_DISTANCE_SENSOR
  if (!beginDistanceSensorOnPins("configured D4/D5", PIN_DISTANCE_SDA, PIN_DISTANCE_SCL)) {
    Serial.println("[ERROR] Distance sensor failed");
    scanI2CBus();

    if (!beginDistanceSensorOnPins("swapped D5/D4", PIN_DISTANCE_SCL, PIN_DISTANCE_SDA)) {
      Serial.println("[ERROR] Distance sensor failed on configured and swapped I2C pins");
      deviceState = STATE_ERROR;
    }
  }
#else
  distanceSensorReady = false;
  Serial.println("[HW] Distance sensor disabled; manual dispense testing only");
#endif

  dispenserServo.attach(PIN_SERVO);
  dispenserServo.write(SERVO_HOME_DEG);
  delay(500);
  Serial.println("[HW] Servo ready");

#if ENABLE_HX711
  Serial.println("[HW] Initialising HX711 on DOUT=D2, SCK=D3");
  scale.begin(PIN_LOADCELL_DOUT, PIN_LOADCELL_SCK);
  if (!waitForHx711Ready(HX711_READY_TIMEOUT_MS)) {
    Serial.println("[ERROR] HX711 not ready after startup retries. Check DT/SCK wiring, power, and pin mapping.");
    deviceState = STATE_ERROR;
  } else {
    Serial.println("[HW] HX711 ready");
  }
#else
  scaleReady = false;
  Serial.println("[HW] HX711 disabled; using estimated liquid weight for this test");
#endif
}

bool waitForHx711Ready(unsigned long timeoutMs) {
#if ENABLE_HX711
  unsigned long startedMs = millis();

  while (millis() - startedMs < timeoutMs) {
    if (scale.is_ready()) {
      scaleReady = true;
      return true;
    }

    delay(HX711_READY_RETRY_MS);
  }

  scaleReady = false;
  return false;
#else
  (void)timeoutMs;
  return false;
#endif
}

bool readLoadCellRawAverage(int sampleCount, long* rawValue) {
#if ENABLE_HX711
  if (!scaleReady && !waitForHx711Ready(HX711_SAMPLE_TIMEOUT_MS)) {
    return false;
  }

  if (!scale.is_ready() && !waitForHx711Ready(HX711_SAMPLE_TIMEOUT_MS)) {
    Serial.println("[WARN] HX711 not ready");
    scaleReady = false;
    return false;
  }

  loadCellRaw = scale.read_average(sampleCount);
  *rawValue = loadCellRaw;
  return true;
#else
  (void)sampleCount;
  (void)rawValue;
  return false;
#endif
}

bool readDistanceMeasurement() {
  if (!distanceSensorReady) {
    return false;
  }

  distanceRawMm = distanceSensor.read();

  if (distanceSensor.timeoutOccurred()) {
    Serial.println("[WARN] Distance sensor timeout");
    return false;
  }

  distanceMm = distanceRawMm - DISTANCE_OFFSET_MM;
  if (distanceMm < 0) {
    distanceMm = 0;
  }

  return true;
}

bool readWeightMeasurement() {
#if ENABLE_HX711
  long rawAverage = 0;
  if (!readLoadCellRawAverage(HX711_READ_SAMPLES, &rawAverage)) {
    return false;
  }

  if (loadCellCalibrationFactor > -0.001 && loadCellCalibrationFactor < 0.001) {
    Serial.println("[CAL] Invalid calibration factor");
    return false;
  }

  liquidWeightGrams = (rawAverage - loadCellZeroRaw) / loadCellCalibrationFactor;

  if (liquidWeightGrams > -EMPTY_NOISE_GRAMS && liquidWeightGrams < EMPTY_NOISE_GRAMS) {
    liquidWeightGrams = 0.0;
  }

  if (liquidWeightGrams < 0.0) {
    liquidWeightGrams = 0.0;
  }

  return true;
#else
  loadCellRaw = 0;
  return false;
#endif
}

void printCalibrationValues() {
#if ENABLE_HX711
  String status = "Zero raw " + String(loadCellZeroRaw) + ", factor " + String(loadCellCalibrationFactor, 6);
  publishCalibrationStatus(status);
  Serial.println("[CAL] Current runtime calibration:");
  Serial.print("[CAL] LOADCELL_ZERO_RAW = ");
  Serial.println(loadCellZeroRaw);
  Serial.print("[CAL] LOADCELL_CALIBRATION_FACTOR = ");
  Serial.println(loadCellCalibrationFactor, 6);
  Serial.print("[CAL] FULL_LIQUID_GRAMS = ");
  Serial.println(FULL_LIQUID_GRAMS, 1);
  Serial.println("[CAL] Copy these values into the constants after a stable calibration.");
#else
  publishCalibrationStatus("HX711 disabled; calibration commands are unavailable");
#endif
}

void tareLoadCell() {
#if ENABLE_HX711
  long rawAverage = 0;
  if (!readLoadCellRawAverage(HX711_CALIBRATION_SAMPLES, &rawAverage)) {
    publishCalibrationStatus("Tare failed: HX711 not ready");
    return;
  }

  loadCellZeroRaw = rawAverage;
  liquidWeightGrams = 0.0;
  previousLiquidWeightGrams = 0.0;
  lastDispenseGrams = 0.0;
  updateRemainingMetrics();
  updateRefillAlert();
  updateStatusLeds();

  publishCalibrationStatus("Empty bottle set to 0 g. Zero raw " + String(loadCellZeroRaw));
  printCalibrationValues();
#else
  publishCalibrationStatus("HX711 disabled; tare skipped");
#endif
}
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
void loop() {
  runBlynkConnection();
#if !USE_MOCK_HARDWARE
  handleSerialCommands();
#endif
  updateStateMachine();
  sampleMeasurementsIfDue();

  if (millis() - lastStatusMs >= STATUS_INTERVAL_MS) {
    lastStatusMs = millis();
    sendStatus();
  }
}

bool readHandDetected() {
#if USE_MOCK_HARDWARE
  if (Serial.available() == 0) {
    return false;
  }

  char command = Serial.read();

  if (command == 'd' || command == 'D') {
    Serial.println("[MOCK] Trigger dispense");
    return true;
  }

  return false;
#else
#if ENABLE_DISTANCE_SENSOR
  if (!readDistanceMeasurement()) {
    return false;
  }
#else
  return false;
#endif

  bool inRange = distanceMm >= MIN_HAND_DISTANCE_MM && distanceMm <= MAX_HAND_DISTANCE_MM;

  if (inRange && !handPresent) {
    handPresent = true;
    updateStatusLeds();
    Serial.print("[DISTANCE] Hand detected at ");
    Serial.print(distanceMm);
    Serial.println(" mm");
    return true;
  }

  if (!inRange) {
    if (handPresent) {
      handPresent = false;
      updateStatusLeds();
    }
  }

  return false;
#endif
}

void performDispense() {
#if USE_MOCK_HARDWARE
  Serial.println("[MOCK] Dispense start");
  delay(200);
  Serial.println("[MOCK] Dispense end");
#else
#if ENABLE_HX711
  readWeightMeasurement();
#endif
  previousLiquidWeightGrams = liquidWeightGrams;

  Serial.println("[SERVO] Press started");

  for (int angle = SERVO_HOME_DEG; angle >= SERVO_PRESS_DEG; angle--) {
    dispenserServo.write(angle);
    delay(SERVO_STEP_DELAY_MS);
  }

  delay(SERVO_HOLD_MS);

  for (int angle = SERVO_PRESS_DEG; angle <= SERVO_HOME_DEG; angle++) {
    dispenserServo.write(angle);
    delay(SERVO_STEP_DELAY_MS);
  }

  delay(SERVO_RETURN_SETTLE_MS);
  Serial.println("[SERVO] Cycle complete");
#endif
}

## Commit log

2026-04-26 feat: add SmartSan software demo workflow
    Prepare the Blynk mapping, mock dashboard controls, and ESP32 firmware skeleton so the software workflow can be tested before the hardware arrives.
    Made-with: Cursor
2026-04-26 Implemented basic pump-count logic and removed weight sensor dependency
2026-04-26 Added basic IR sensor detection with debounce and edge triggering, updated pins to pump count intstead of weight
2026-04-28 added initial servo control for dispensing cycle (mock-safe skeleton)
2026-04-28 finalised servo integration with mock/hardware separation + state machine stability fixes (mock testing)
    [SmartSanESP32.ino]
2026-04-29 feat: enhance dashboard sync and pump-count contract
    Align the front-end mock dashboard, data contract docs, and test plan with the pump-count firmware prototype.
    Adds sync-health indicators, event timeline, and dashboard controls for failure simulation.
    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
    [SmartSanESP32.ino]
2026-04-30 Added error recovery and stabilise watchdog
    [SmartSanESP32.ino]
2026-04-30 Added Blynk reconnection and fail handling
    [SmartSanESP32.ino]
2026-04-30 Revert "Added Blynk reconnection and fail handling"
    This reverts commit 14a9ad55b2f9b594ca8671dfcbd8bb1d39c23a6.
    Realised overlap with the work another team member is doing to avoid merge conflicts.
    [SmartSanESP32.ino]
2026-04-30 Fixed compile errors, core firmware logic and safety logic is done, Hardware validation + UI + system testing is not done yet
    [SmartSanESP32.ino]
2026-05-01 docs: added firmware output contract and mock state traces
2026-05-01 fix: reset safety flag and align mock trace with firmware reset flow
    [SmartSanESP32.ino]
2026-05-05 v2: Add panels — prediction, usage chart, activity feed, operator controls
2026-05-05 v2: Replace dashboard logic with device+prediction model, charting, feed, and controls
2026-05-21 feature: speed servo
2026-05-21 fix: remove restrition in servo
    [SmartSanESP32.ino]
